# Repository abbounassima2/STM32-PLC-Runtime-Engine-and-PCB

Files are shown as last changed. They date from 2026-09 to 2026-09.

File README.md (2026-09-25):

# STM32 PLC Runtime Engine and Hardware Design

An STM32F407-based PLC runtime engine developed in Embedded C, together with a custom PLC controller PCB and a Renode-based simulation environment.

The project focuses on designing a **reusable PLC runtime platform** rather than a single-purpose STM32 application. The architecture separates the permanent runtime, hardware abstraction, process image, communication, and user control logic.

---

## Project Goal

The main objective is to develop an embedded PLC platform capable of providing the core functions of a programmable industrial controller:

- PLC operating modes
- Cyclic and periodic program execution
- Process-image based I/O
- Digital and analog I/O management
- Retentive PLC variables
- Industrial communication
- Runtime monitoring
- Real-time task management
- Custom PLC hardware
- Firmware simulation and testing

The long-term architecture is based on separating the **permanent PLC runtime** from the **user program**, providing the foundation for a configurable and programmable embedded PLC.

---

## System Architecture

```text
                  PLC User Program
                         │
                         ▼
              ┌─────────────────────┐
              │    PLC Runtime       │
              │                      │
              │  Scheduler           │
              │  Operating Modes     │
              │  Process Image       │
              │  I/O Management      │
              │  Retentive Memory    │
              │  Error Handling      │
              │  Communication       │
              └──────────┬───────────┘
                         │
                         ▼
                    STM32F407
                         │
             ┌───────────┼───────────┐
             ▼           ▼           ▼
          Digital      Analog      RS485 /
             I/O         I/O       Modbus

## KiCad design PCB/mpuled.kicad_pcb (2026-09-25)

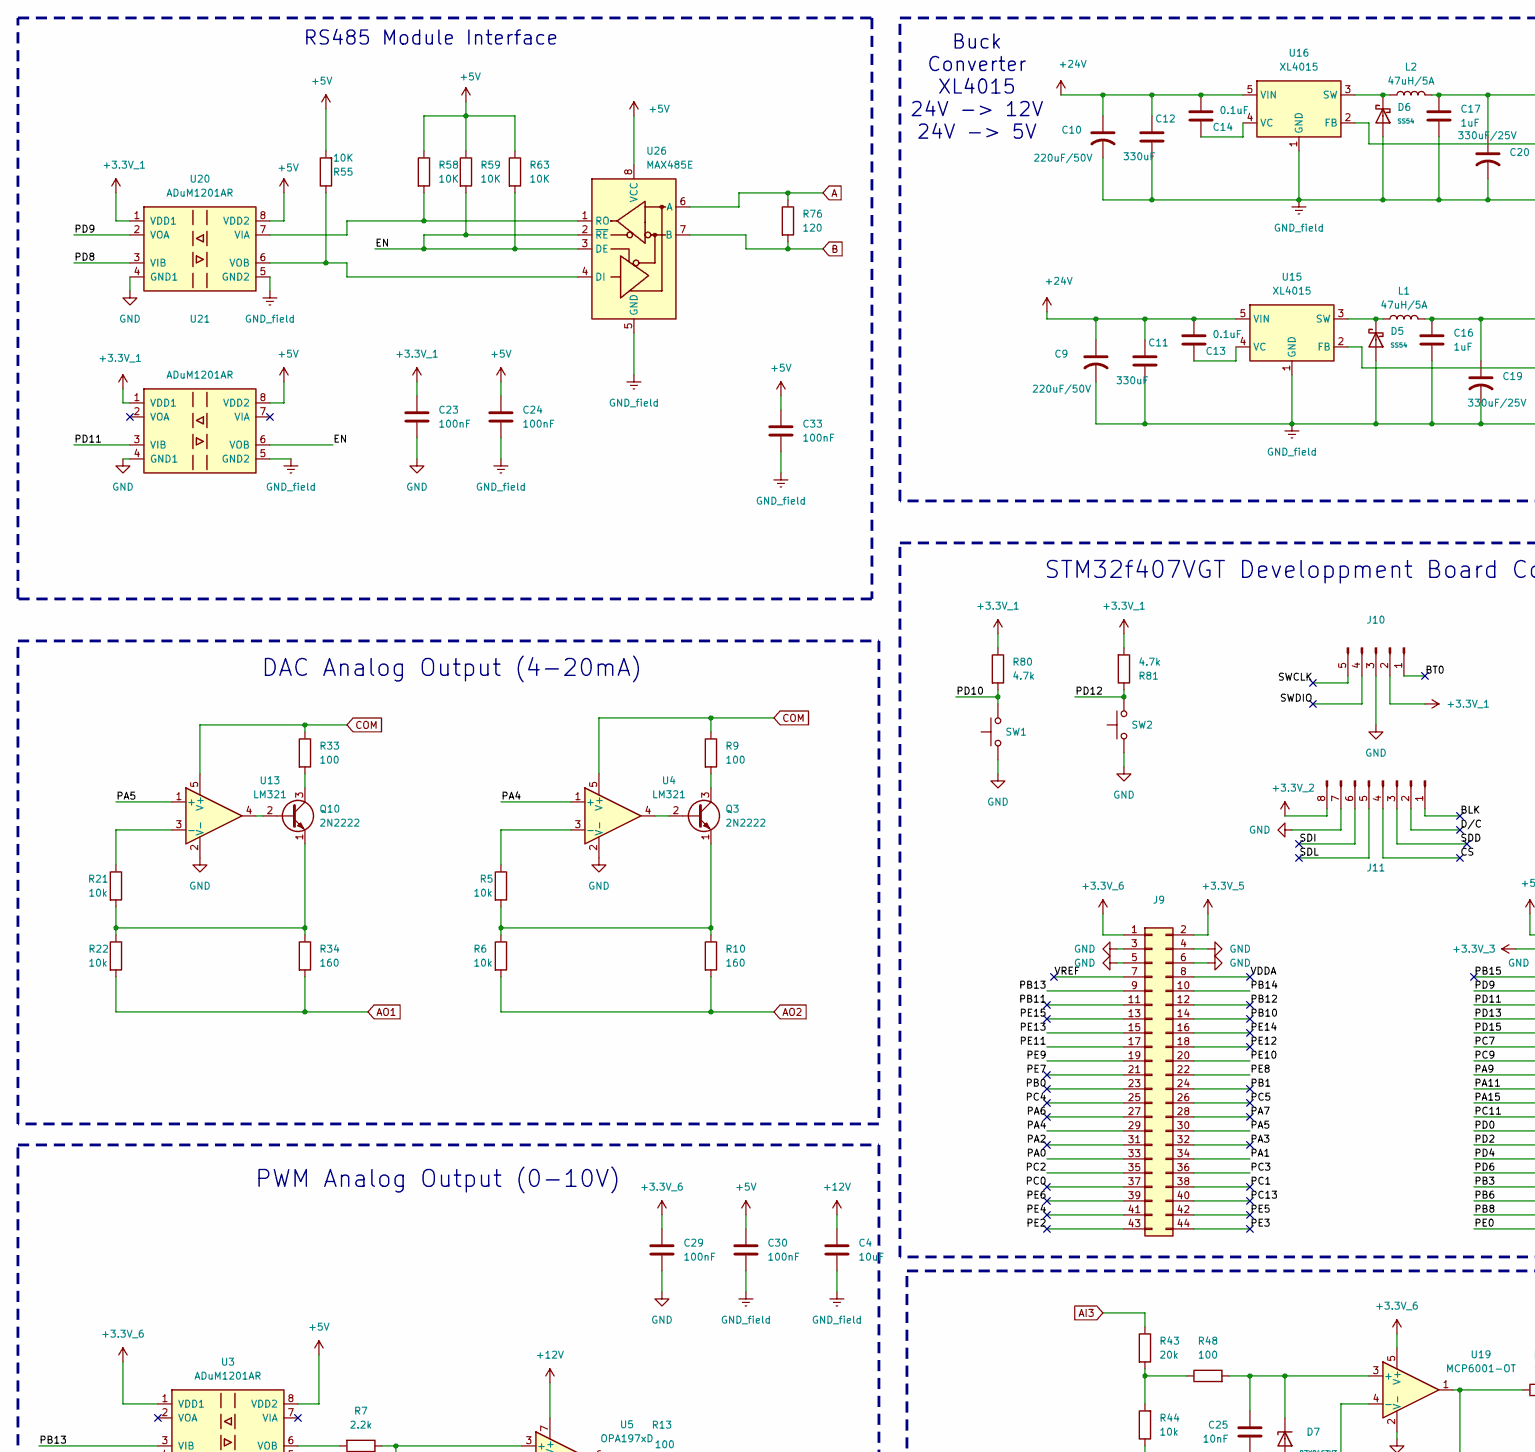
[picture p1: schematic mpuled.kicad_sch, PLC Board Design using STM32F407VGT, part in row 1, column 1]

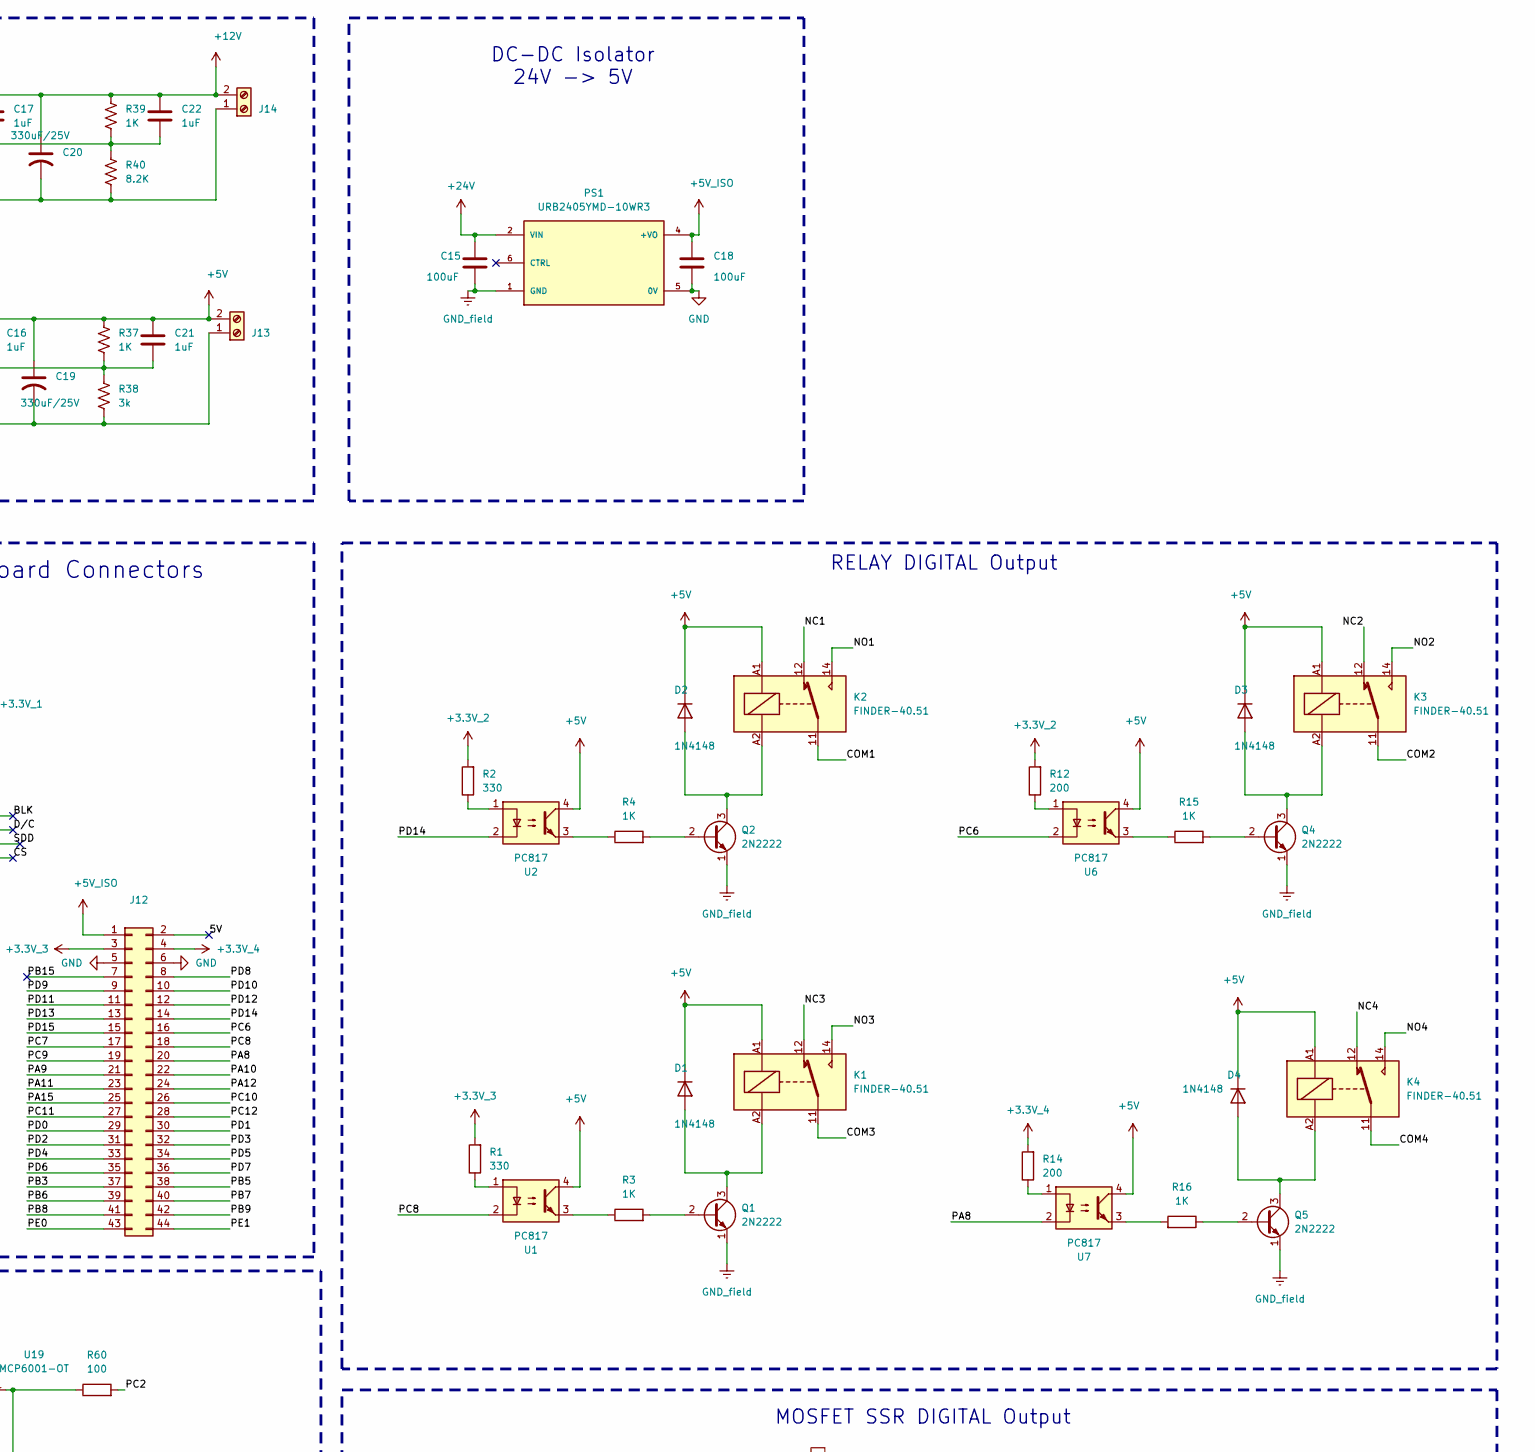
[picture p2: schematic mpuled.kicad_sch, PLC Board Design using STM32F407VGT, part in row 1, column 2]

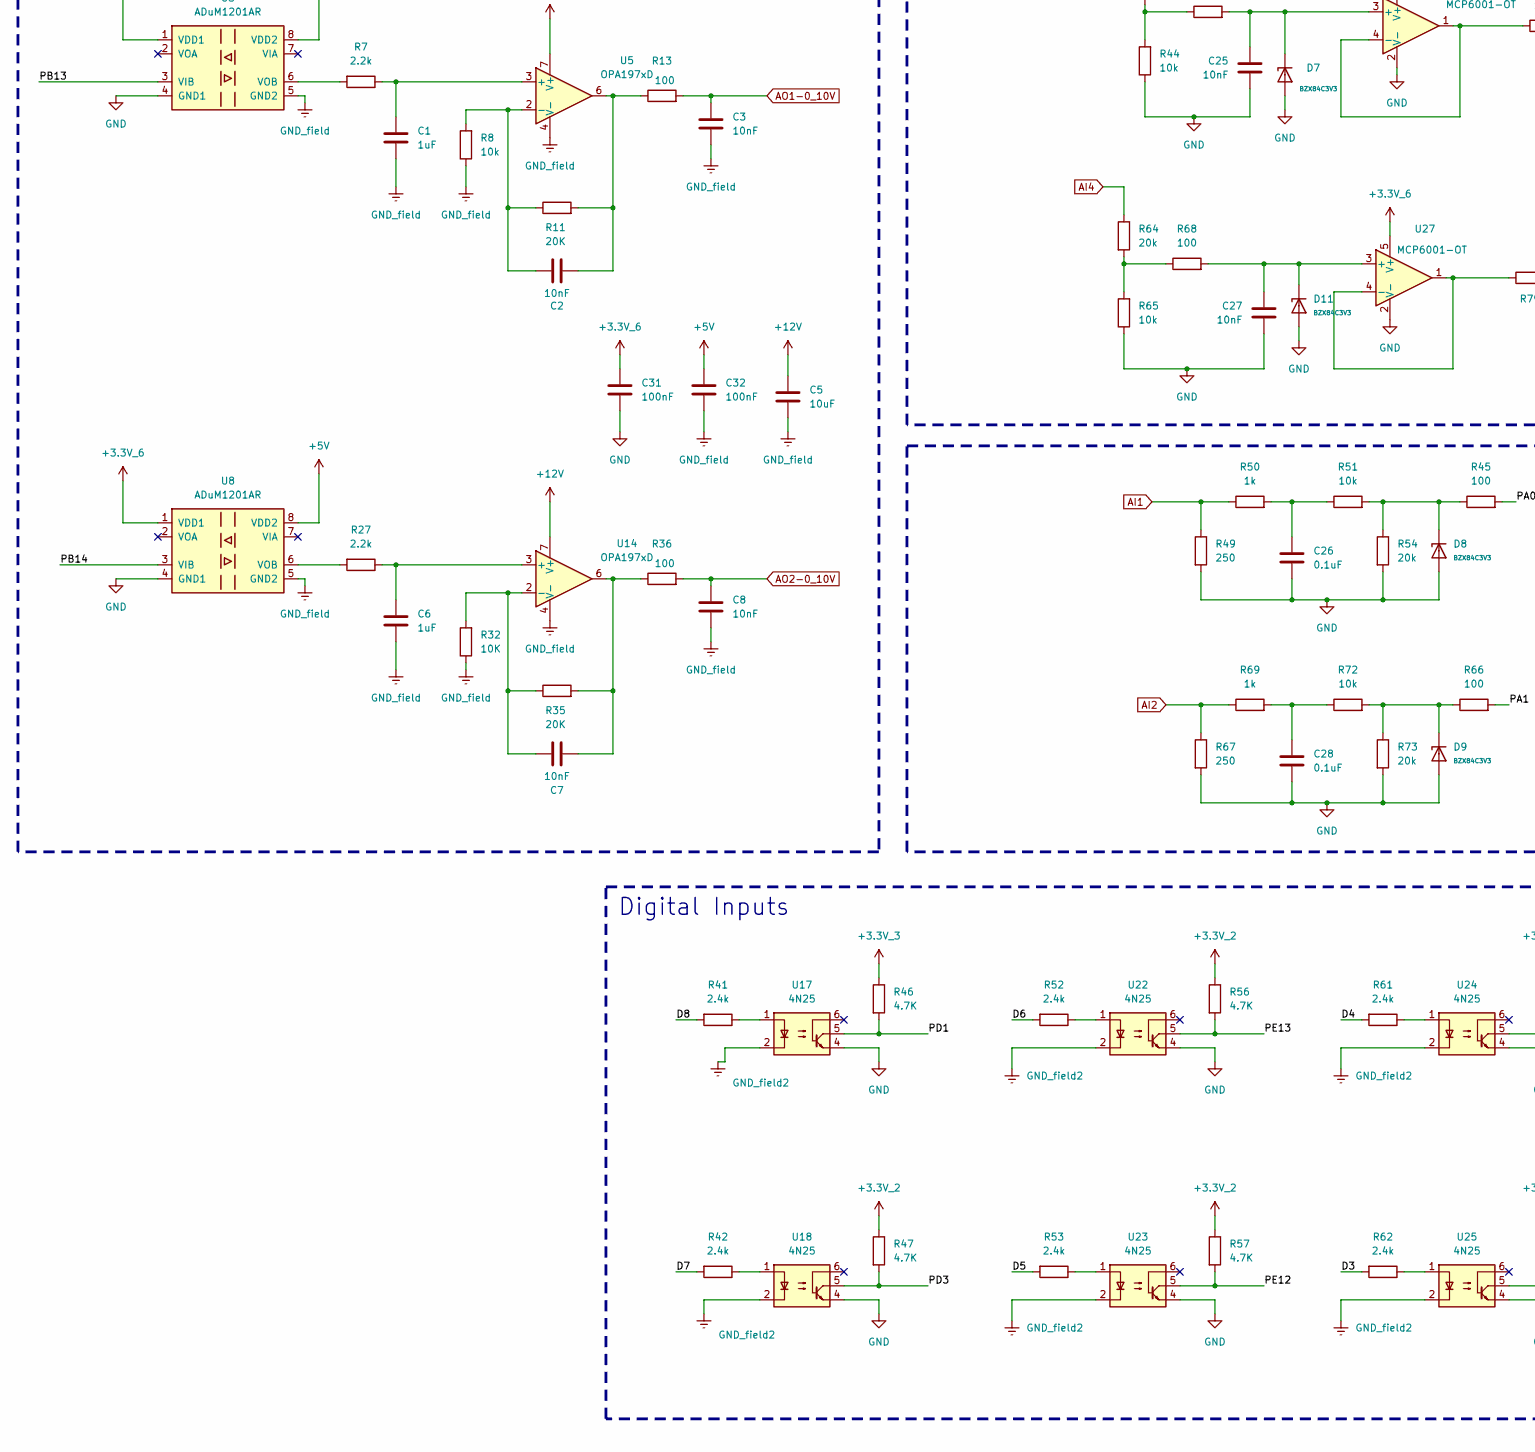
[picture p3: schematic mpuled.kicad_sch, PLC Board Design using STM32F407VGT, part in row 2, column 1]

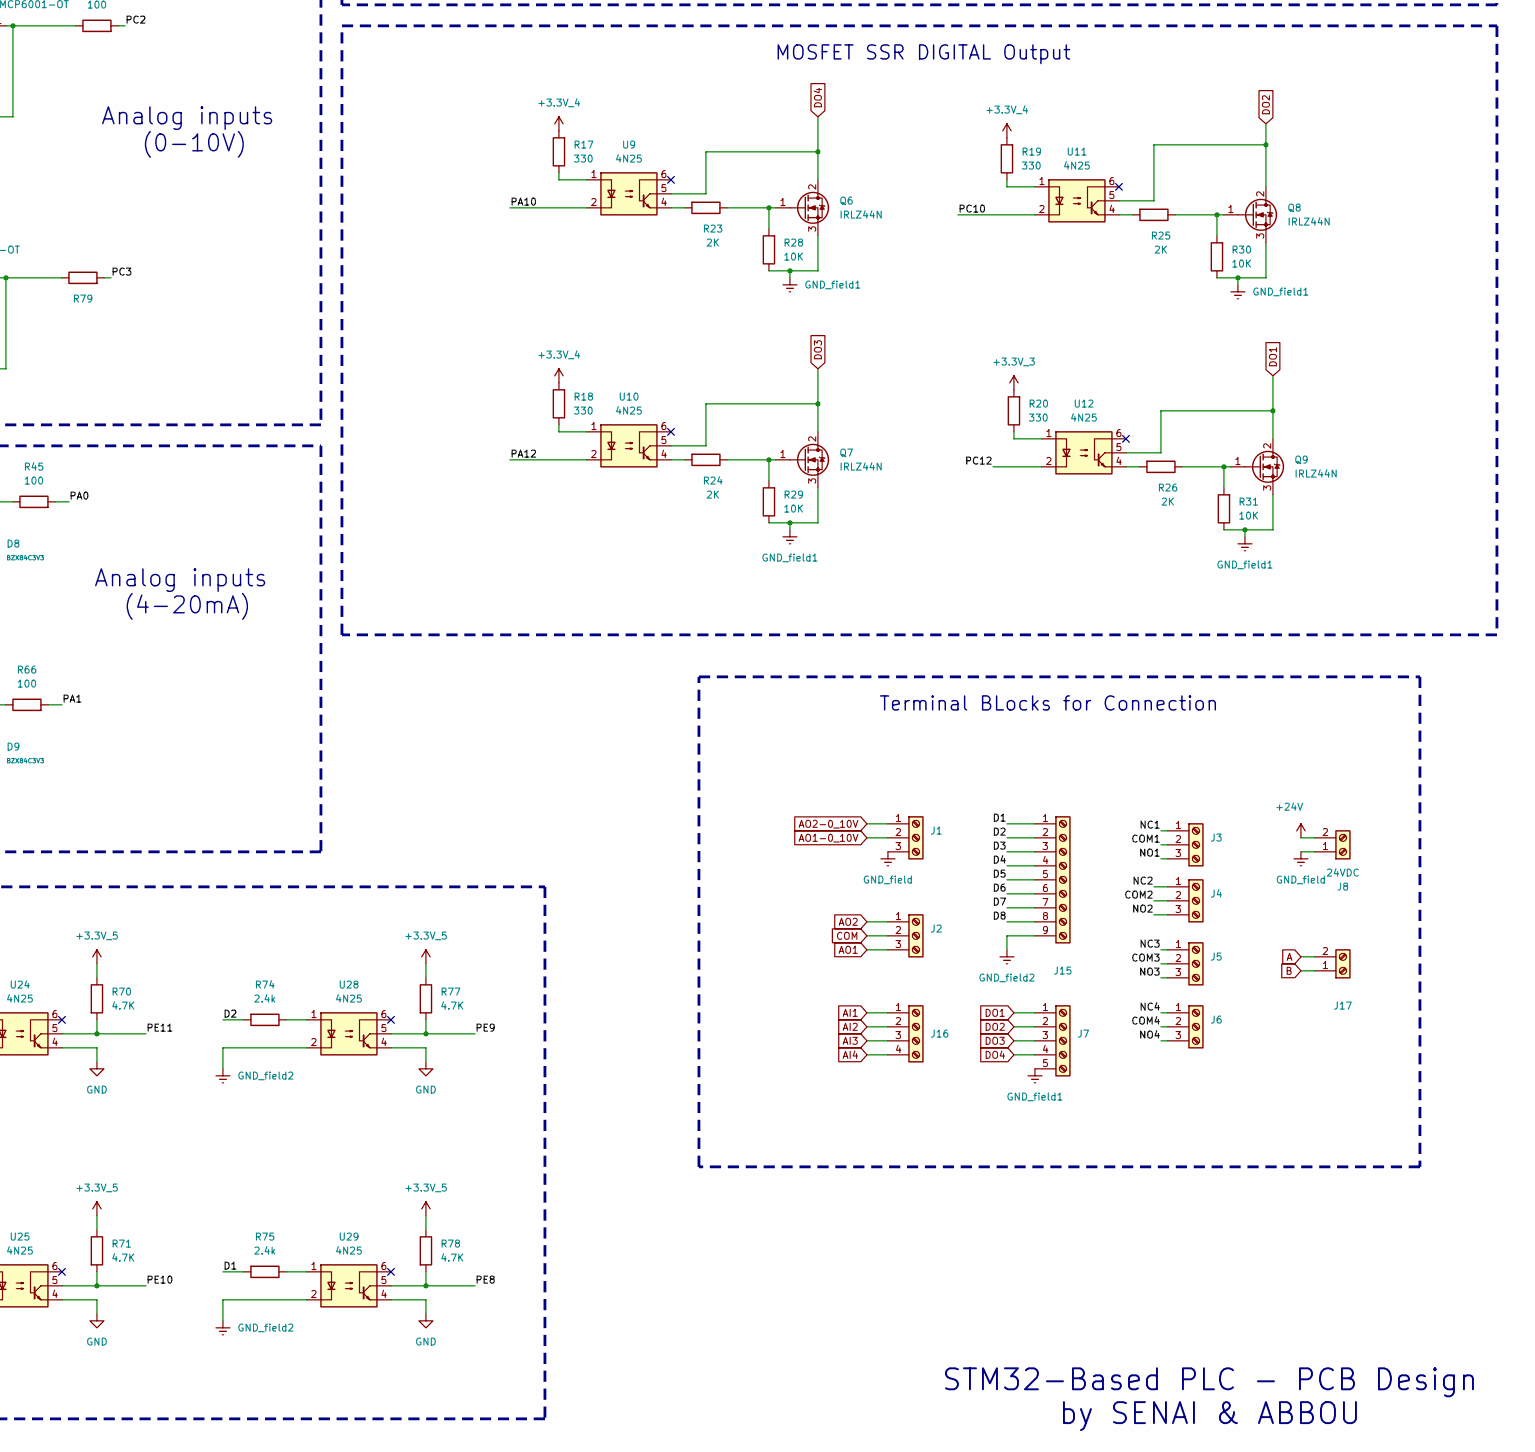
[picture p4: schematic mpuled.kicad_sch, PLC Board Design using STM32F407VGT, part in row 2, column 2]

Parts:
C1, C6, C16, C17, C21, C22: 1uF; C_1206_3216Metric_Pad1.33x1.80mm_HandSolder
C2, C3, C7, C8, C25, C27: 10nF; C_1206_3216Metric_Pad1.33x1.80mm_HandSolder
C4, C5: 10uF; C_1206_3216Metric_Pad1.33x1.80mm_HandSolder
C9, C10: 220uF/50V; C_Radial_D10.0mm_H12.5mm_P5.00mm
C11, C12: 330uF; C_1206_3216Metric_Pad1.33x1.80mm_HandSolder
C13, C14, C26, C28: 0.1uF; C_1206_3216Metric_Pad1.33x1.80mm_HandSolder
C15, C18: 100uF; C_1206_3216Metric_Pad1.33x1.80mm_HandSolder
C19, C20: 330uF/25V; C_Radial_D10.0mm_H12.5mm_P5.00mm
C23, C24, C29, C30, C31, C32, C33: 100nF; C_1206_3216Metric_Pad1.33x1.80mm_HandSolder
D1, D2, D3, D4: 1N4148; D_DO-35_SOD27_P7.62mm_Horizontal
D5, D6: SS54; D_SMA; Forward Voltage (Vf@If) 550mV@5A; Reverse Voltage (Vr) 40V; Part SS54; LCSC C22452
D7, D8, D9, D11: BZX84C3V3; D_SOT-23; Zener Voltage (Range) 3.1V~3.5V; Zener Voltage (Nom) 3.3V; Part BZX84C3V3; LCSC C19077467
J1, J2: Screw_Terminal_01x03; TerminalBlock_Phoenix_MKDS-1,5-3_1x03_P5.00mm_Horizontal
J3, J4, J5, J6: TerminalBlock_Phoenix_MKDS-1,5-3-5.08_1x03_P5.08mm_Horizont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
J7: Screw_Terminal_01x05; TerminalBlock_Phoenix_MKDS-1,5-5-5.08_1x05_P5.08mm_Horizont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
J8: 24VDC; TerminalBlock_Phoenix_MKDS-1,5-2-5.08_1x02_P5.08mm_Horizont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
J9, J12: Conn_02x22_Odd_Even; PinHeader_2x22_P2.54mm_Vertical
J10: PinHeader_1x05_P2.54mm_Vertical
J11: PinHeader_1x08_P2.54mm_Vertical
J13, J14: Screw_Terminal_01x02; TerminalBlock_Phoenix_MKDS-1,5-2_1x02_P5.00mm_Horizontal
J15: Screw_Terminal_01x09; TerminalBlock_Phoenix_MKDS-1,5-9-5.08_1x09_P5.08mm_Horizont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
J16: TerminalBlock_Phoenix_MKDS-1,5-4_1x04_P5.00mm_Horizontal
J17: TerminalBlock_Phoenix_MKDS-1,5-2-5.08_1x02_P5.08mm_Horizont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
K1, K2, K3, K4: FINDER-40.51; Relay_SPDT_Finder_40.51
L1, L2: 47uH/5A; L_Axial_L14.5mm_D5.8mm_P20.32mm_Horizontal_Fastron_HBCC
PS1: URB2405YMD-10WR3; Converter_DCDC_XP_POWER-IAxxxxS_THT; PARTREV 2019.11.13-A/9
Q1, Q4, Q5: 2N2222; SOT-23W_Handsoldering
Q2: 2N2222; TSOT-23_HandSoldering
Q3, Q10: 2N2222; Q_SOT-23
Q6, Q7, Q8, Q9: IRLZ44N; TO-220-3_Vertical
R1, R2, R17, R18, R19, R20: 330; R_1206_3216Metric_Pad1.30x1.75mm_HandSolder
R3, R4, R15, R16, R37, R39: 1K; R_1206_3216Metric_Pad1.30x1.75mm_HandSolder
R5, R6, R8, R21, R22, R44, R51, R65, R72: 10k; R_1206_3216Metric_Pad1.30x1.75mm_HandSolder
R7, R27: 2.2k; R_1206_3216Metric_Pad1.30x1.75mm_HandSolder
R9, R13, R33, R36, R45, R60, R66, R79: 100; R_1206_3216Metric_Pad1.30x1.75mm_HandSolder
R10, R34: 160; R_1206_3216Metric_Pad1.30x1.75mm_HandSolder
R11, R35: 20K; R_1206_3216Metric_Pad1.30x1.75mm_HandSolder
R12, R14: 200; R_1206_3216Metric_Pad1.30x1.75mm_HandSolder
R23, R24, R25, R26: 2K; R_1206_3216Metric_Pad1.30x1.75mm_HandSolder
R28, R29, R30, R31, R32, R55, R58, R59, R63: 10K; R_1206_3216Metric_Pad1.30x1.75mm_HandSolder
R38: 3k; R_1206_3216Metric_Pad1.30x1.75mm_HandSolder
R40: 8.2K; R_1206
R41, R42, R52, R53, R61, R62, R74, R75: 2.4k; R_1206_3216Metric_Pad1.30x1.75mm_HandSolder
R43, R54, R73: 20k; R_1206_3216Metric_Pad1.30x1.75mm_HandSolder
R46, R47, R56, R57, R70, R71, R77, R78: 4.7K; R_1206_3216Metric_Pad1.30x1.75mm_HandSolder
R48, R68: 100; R_1206_3216Metric
R49, R67: 250; R_1206_3216Metric_Pad1.30x1.75mm_HandSolder
R50, R69: 1k; R_1206_3216Metric_Pad1.30x1.75mm_HandSolder
R64: 20k; R_1206_3216Metric
R76: 120; R_1206_3216Metric_Pad1.30x1.75mm_HandSolder
R80, R81: 4.7k; R_1206_3216Metric_Pad1.30x1.75mm_HandSolder
SW1, SW2: SW_Omron_B3FS; SW_SPST_Omron_B3FS-100xP
U1, U2, U6, U7: PC817; DIP-4_W7.62mm
U3, U8, U20, U21: ADuM1201AR; SOIC-8_3.9x4.9mm_P1.27mm
U4, U13: LM321; SOT-23-5_HandSoldering
U5, U14: OPA197xD; SOIC-8_3.9x4.9mm_P1.27mm
U9, U10, U11, U12, U17, U18, U22, U23, U24, U25, U28, U29: 4N25; DIP-6_W7.62mm
U15, U16: XL4015; TO-263-5_TabPin3
U19, U27: MCP6001-OT; SOT-23-5
U26: MAX485E; SOIC-8_3.9x4.9mm_P1.27mm

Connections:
+3.3V_1: C23.1, J10.2, R80.1, R81.2, U20.1 (VDD1), U21.1 (VDD1)
+3.3V_2: J11.8, R2.2, R12.2, R47.1, R56.1, R57.1
+3.3V_3: J12.3, R1.2, R20.2, R46.1
+3.3V_4: J12.4, R14.2, R17.2, R18.2, R19.2
+3.3V_5: J9.2, R70.1, R71.1, R77.1, R78.1
+3.3V_6: C29.1, C31.1, J9.1, U3.1 (VDD1), U8.1 (VDD1), U19.5 (V+), U27.5 (V+)
+5V: C16.1, C19.1, C21.1, C24.1, C30.1, C32.1, C33.1, D1.1 (K), D2.1 (K), D3.1 (K), D4.1 (K), J13.2, K1.A1, K2.A1, K3.A1, K4.A1, L1.2, R37.1, R55.2, R58.1, R59.1, R63.1, U1.4, U2.4, U3.8 (VDD2), U6.4, U7.4, U8.8 (VDD2), U20.8 (VDD2), U21.8 (VDD2), U26.8 (VCC)
+5V_ISO: C18.1, J12.1, PS1.4 (+VO)
+12V: C4.1, C5.1, C17.1, C20.1, C22.1, J14.2, L2.2, R39.1, U5.7 (V+), U14.7 (V+)
+24V: C9.1, C10.1, C11.1, C12.1, C13.1, C14.1, C15.1, J8.2, PS1.2 (VIN), U15.5 (VIN), U16.5 (VIN)
/5V: J12.2
/BLK: J11.1
/BT0: J10.1
/COM1: J3.2, K2.11
/COM2: J4.2, K3.11
/COM3: J5.2, K1.11
/COM4: J6.2, K4.11
/CS: J11.4
/D1: J15.1, R75.2
/D2: J15.2, R74.2
/D3: J15.3, R62.2
/D4: J15.4, R61.2
/D5: J15.5, R53.2
/D6: J15.6, R52.2
/D7: J15.7, R42.2
/D8: J15.8, R41.2
/D/C: J11.2
/EN: R59.2, R63.2, U21.6 (VOB), U26.2 (~RE), U26.3 (DE)
/NC1: J3.1, K2.12
/NC2: J4.1, K3.12
/NC3: J5.1, K1.12
/NC4: J6.1, K4.12
/NO1: J3.3, K2.14
/NO2: J4.3, K3.14
/NO3: J5.3, K1.14
/NO4: J6.3, K4.14
/PA0: J9.33, R45.2
/PA1: J9.34, R66.2
/PA2: J9.31
/PA3: J9.32
/PA4: J9.29, U4.1 (+)
/PA5: J9.30, U13.1 (+)
/PA6: J9.27
/PA7: J9.28
/PA8: J12.20, U7.2
/PA9: J12.21
/PA10: J12.22, U9.2
/PA11: J12.23
/PA12: J12.24, U10.2
/PA15: J12.25
/PB0: J9.23
/PB1: J9.24
/PB3: J12.37
/PB5: J12.38
/PB6: J12.39
/PB7: J12.40
/PB8: J12.41
/PB9: J12.42
/PB10: J9.14
/PB11: J9.11
/PB12: J9.12
/PB13: J9.9, U3.3 (VIB)
/PB14: J9.10, U8.3 (VIB)
/PB15: J12.7
/PC0: J9.37
/PC1: J9.38
/PC2: J9.35, R60.2
/PC3: J9.36, R79.2
/PC4: J9.25
/PC5: J9.26
/PC6: J12.16, U6.2
/PC7: J12.17
/PC8: J12.18, U1.2
/PC9: J12.19
/PC10: J12.26, U11.2
/PC11: J12.27
/PC12: J12.28, U12.2
/PC13: J9.40
/PD0: J12.29
/PD1: J12.30, R46.2, U17.5
/PD2: J12.31
/PD3: J12.32, R47.2, U18.5
/PD4: J12.33
/PD5: J12.34
/PD6: J12.35
/PD7: J12.36
/PD8: J12.8, U20.3 (VIB)
/PD9: J12.9, U20.2 (VOA)
/PD10: J12.10, R80.2, SW1.2
/PD11: J12.11, U21.3 (VIB)
/PD12: J12.12, R81.1, SW2.2
/PD13: J12.13
/PD14: J12.14, U2.2
/PD15: J12.15
/PE0: J12.43
/PE1: J12.44
/PE2: J9.43
/PE3: J9.44
/PE4: J9.41
/PE5: J9.42
/PE6: J9.39
/PE7: J9.21
/PE8: J9.22, R78.2, U29.5
/PE9: J9.19, R77.2, U28.5
/PE10: J9.20, R71.2, U25.5
/PE11: J9.17, R70.2, U24.5
/PE12: J9.18, R57.2, U23.5
/PE13: J9.15, R56.2, U22.5
/PE14: J9.16
/PE15: J9.13
/SDD: J11.3
/SDI: J11.6
/SDL: J11.5
/SWCLK: J10.5
/SWDIO: J10.4
/VDDA: J9.8
/VREF: J9.7
A: J17.2, R76.1, U26.6 (A)
AI1: J16.1, R49.1, R50.1
AI2: J16.2, R67.1, R69.1
AI3: J16.3, R43.1
AI4: J16.4, R64.1
AO1: J2.3, R22.2, R34.2
AO1-0_10V: C3.1, J1.2, R13.2
AO2: J2.1, R6.2, R10.2
AO2-0_10V: C8.1, J1.1, R36.2
B: J17.1, R76.2, U26.7 (B)
COM: J2.2, R9.1, R33.1, U4.5 (V+), U13.5 (V+)
DO1: J7.1, Q9.2 (D), U12.5
DO2: J7.2, Q8.2 (D), U11.5
DO3: J7.3, Q7.2 (D), U10.5
DO4: J7.4, Q6.2 (D), U9.5
GND: C18.2, C23.2, C25.2, C26.2, C27.2, C28.2, C29.2, C31.2, D7.1, D8.1, D9.1, D11.1, J9.3, J9.4, J9.5, J9.6, J10.3, J11.7, J12.5, J12.6, PS1.5 (0V), R44.1, R49.2, R54.2, R65.1, R67.2, R73.2, SW1.1, SW2.1, U3.4 (GND1), U4.2 (V-), U8.4 (GND1), U13.2 (V-), U17.4, U18.4, U19.2 (V-), U20.4 (GND1), U21.4 (GND1), U22.4, U23.4, U24.4, U25.4, U27.2 (V-), U28.4, U29.4
GND_field: C1.2, C3.2, C4.2, C5.2, C6.2, C8.2, C9.2, C10.2, C11.2, C12.2, C15.2, C16.2, C17.2, C19.2, C20.2, C24.2, C30.2, C32.2, C33.2, D5.2, D6.2, J1.3, J8.1, J13.1, J14.1, PS1.1 (GND), Q1.1 (E), Q2.1 (E), Q4.1 (E), Q5.1 (E), R8.1, R32.1, R38.2, R40.2, U3.5 (GND2), U5.4 (V-), U8.5 (GND2), U14.4 (V-), U15.1 (GND), U16.1 (GND), U20.5 (GND2), U21.5 (GND2), U26.5 (GND)
GND_field1: J7.5, Q6.3 (S), Q7.3 (S), Q8.3 (S), Q9.3 (S), R28.1, R29.1, R30.1, R31.1
GND_field2: J15.9, U17.2, U18.2, U22.2, U23.2, U24.2, U25.2, U28.2, U29.2
unnamed: C2.2, R11.2, R13.1, U5.6
unnamed: C7.2, R35.2, R36.1, U14.6
unnamed: C26.1, R50.2, R51.1
unnamed: C28.1, R69.2, R72.1
unnamed: D1.2 (A), K1.A2, Q1.3 (C)
unnamed: D2.2 (A), K2.A2, Q2.3 (C)
unnamed: D3.2 (A), K3.A2, Q4.3 (C)
unnamed: D4.2 (A), K4.A2, Q5.3 (C)
unnamed: D8.3, R45.1, R51.2, R54.1
unnamed: D9.3, R66.1, R72.2, R73.1
unnamed: Q1.2 (B), R3.2
unnamed: Q2.2 (B), R4.2
unnamed: Q3.2 (B), U4.4
unnamed: Q3.3 (C), R9.2
unnamed: Q3.1 (E), R5.2, R6.1, R10.1
unnamed: Q4.2 (B), R15.2
unnamed: Q5.2 (B), R16.1
unnamed: Q6.1 (G), R23.1, R28.2
unnamed: Q7.1 (G), R24.1, R29.2
unnamed: Q8.1 (G), R25.1, R30.2
unnamed: Q9.1 (G), R26.1, R31.2
unnamed: Q10.2 (B), U13.4
unnamed: Q10.3 (C), R33.2
unnamed: Q10.1 (E), R21.2, R22.1, R34.1
unnamed: R1.1, U1.1
unnamed: R2.1, U2.1
unnamed: R3.1, U1.3
unnamed: R4.1, U2.3
unnamed: R12.1, U6.1
unnamed: R14.1, U7.1
unnamed: R15.1, U6.3
unnamed: R16.2, U7.3
unnamed: R17.1, U9.1
unnamed: R18.1, U10.1
unnamed: R19.1, U11.1
unnamed: R20.1, U12.1
unnamed: R23.2, U9.4
unnamed: R24.2, U10.4
unnamed: R25.2, U11.4
unnamed: R26.2, U12.4
unnamed: R41.1, U17.1
unnamed: R42.1, U18.1
unnamed: R43.2, R44.2, R48.1
unnamed: R52.1, U22.1
unnamed: R53.1, U23.1
unnamed: R61.1, U24.1
unnamed: R62.1, U25.1
unnamed: R64.2, R65.2, R68.1
unnamed: R74.1, U28.1
unnamed: R75.1, U29.1
unnamed: R7.2, U3.6 (VOB)
unnamed: R5.1, U4.3 (-)
unnamed: C1.1, R7.1, U5.3 (+)
unnamed: C2.1, R8.2, R11.1, U5.2 (-)
unnamed: R27.2, U8.6 (VOB)
unnamed: R21.1, U13.3 (-)
unnamed: C6.1, R27.1, U14.3 (+)
unnamed: C7.1, R32.2, R35.1, U14.2 (-)
unnamed: C21.2, R37.2, R38.1, U15.2 (FB)
unnamed: D5.1, L1.1, U15.3 (SW)
unnamed: C13.2, U15.4 (VC)
unnamed: C22.2, R39.2, R40.1, U16.2 (FB)
unnamed: D6.1, L2.1, U16.3 (SW)
unnamed: C14.2, U16.4 (VC)
unnamed: C25.1, D7.3, R48.2, U19.3 (+)
unnamed: R60.1, U19.1, U19.4 (-)
unnamed: R58.2, U20.7 (VIA), U26.1 (RO)
unnamed: R55.1, U20.6 (VOB), U26.4 (DI)
unnamed: C27.1, D11.3, R68.2, U27.3 (+)
unnamed: R79.1, U27.1, U27.4 (-)

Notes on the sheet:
DC-DC Isolator 24V -> 5V
RELAY DIGITAL Output
Buck Converter XL4015 24V -> 12V 24V -> 5V
DAC Analog Output (4-20mA)
RS485 Module Interface
Analog inputs (4-20mA)
STM32-Based PLC - PCB Design by SENAI & ABBOU
Terminal BLocks for Connection
Digital Inputs
MOSFET SSR DIGITAL Output
Analog inputs (0-10V)
PWM Analog Output (0-10V)
STM32f407VGT Developpment Board Connectors

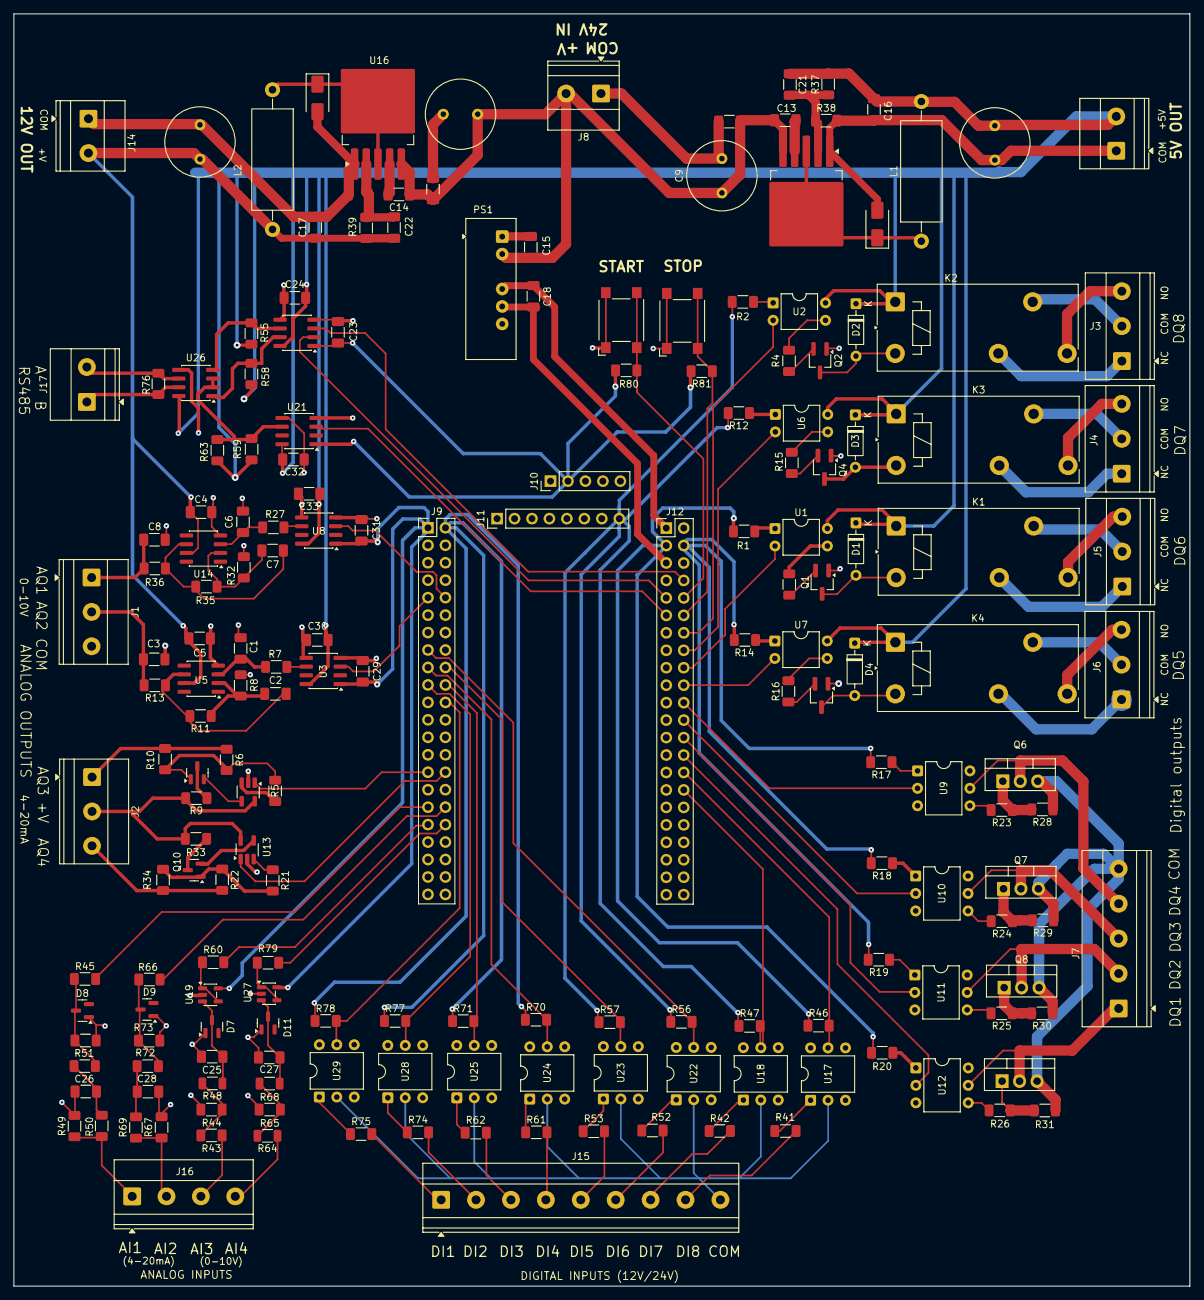
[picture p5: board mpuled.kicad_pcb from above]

Board: 2 copper layers, 171.1 x 185.1 mm, 189 parts (0 on the bottom side), 149 nets.

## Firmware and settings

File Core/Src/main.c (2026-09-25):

#include "main.h"
#include "cmsis_os.h"

#include "board.h"
#include "plc_scheduler.h"
#include "comm_rs485.h"
#include "retentive.h"

/* --- Peripheral handles  --- */
ADC_HandleTypeDef  hadc1;
DAC_HandleTypeDef  hdac;
TIM_HandleTypeDef  htim2;
TIM_HandleTypeDef  htim12;
UART_HandleTypeDef huart4;
UART_HandleTypeDef huart3;

/* --- RTOS thread handles/attributes --- */
osThreadId_t defaultTaskHandle;
const osThreadAttr_t defaultTask_attributes = {
    .name = "defaultTask",
    .stack_size = 512 * 4,
    .priority = (osPriority_t) osPriorityNormal,
};

osThreadId_t ob30TaskHandle;
const osThreadAttr_t ob30Task_attributes = {
    .name = "ob30Task",
    .stack_size = 512 * 4,
    .priority = (osPriority_t) osPriorityHigh,
};

osThreadId_t commTaskHandle;
const osThreadAttr_t commTask_attributes = {
    .name = "commTask",
    .stack_size = 256 * 4,
    .priority = (osPriority_t) osPriorityLow,
};


void SystemClock_Config(void);
static void MX_GPIO_Init(void);
static void MX_ADC1_Init(void);
static void MX_DAC_Init(void);
static void MX_TIM2_Init(void);
static void MX_TIM12_Init(void);
static void MX_UART4_Init(void);
static void MX_USART3_UART_Init(void);

int main(void)
{
    HAL_Init();
    SystemClock_Config();

    MX_GPIO_Init();
    MX_ADC1_Init();
    MX_DAC_Init();
    MX_TIM2_Init();
    MX_TIM12_Init();
    MX_UART4_Init();
    MX_USART3_UART_Init();

    PLC_RS485_Init();

    osKernelInitialize();

    defaultTaskHandle = osThreadNew(state_machine, NULL, &defaultTask_attributes);
    ob30TaskHandle     = osThreadNew(OB30_Task, NULL, &ob30Task_attributes);
    commTaskHandle      = osThreadNew(CommTask, NULL, &commTask_attributes);

    osKernelStart();

    while (1) { }
}




void HAL_TIM_PeriodElapsedCallback(TIM_HandleTypeDef *htim)
{
    if (htim->Instance == TIM2) {
        OB80_ISR_Handler();
    }
}



void Error_Handler(void)
{
    __disable_irq();
    while (1) { }
}

/* --- printf() redirection to UART4, used by update_output()'s
 *     diagnostic line in process_image.c --- */
int _write(int file, char *ptr, int len)
{
    (void)file;
    HAL_UART_Transmit(&huart4, (uint8_t *)ptr, len, HAL_MAX_DELAY);
    return len;
}

void SystemClock_Config(void)
{
  RCC_OscInitTypeDef RCC_OscInitStruct = {0};
  RCC_ClkInitTypeDef RCC_ClkInitStruct = {0};


  __HAL_RCC_PWR_CLK_ENABLE();
  __HAL_PWR_VOLTAGESCALING_CONFIG(PWR_REGULATOR_VOLTAGE_SCALE1);


  RCC_OscInitStruct.OscillatorType = RCC_OSCILLATORTYPE_HSI;
  RCC_OscInitStruct.HSIState = RCC_HSI_ON;
  RCC_OscInitStruct.HSICalibrationValue = RCC_HSICALIBRATION_DEFAULT;
  RCC_OscInitStruct.PLL.PLLState = RCC_PLL_ON;
  RCC_OscInitStruct.PLL.PLLSource = RCC_PLLSOURCE_HSI;
  RCC_OscInitStruct.PLL.PLLM = 16;
  RCC_OscInitStruct.PLL.PLLN = 336;
  RCC_OscInitStruct.PLL.PLLP = RCC_PLLP_DIV2;
  RCC_OscInitStruct.PLL.PLLQ = 4;
  if (HAL_RCC_OscConfig(&RCC_OscInitStruct) != HAL_OK)
  {
    Error_Handler();
  }


  RCC_ClkInitStruct.ClockType = RCC_CLOCKTYPE_HCLK|RCC_CLOCKTYPE_SYSCLK
                              |RCC_CLOCKTYPE_PCLK1|RCC_CLOCKTYPE_PCLK2;
  RCC_ClkInitStruct.SYSCLKSource = RCC_SYSCLKSOURCE_PLLCLK;
  RCC_ClkInitStruct.AHBCLKDivider = RCC_SYSCLK_DIV1;
  RCC_ClkInitStruct.APB1CLKDivider = RCC_HCLK_DIV4;
  RCC_ClkInitStruct.APB2CLKDivider = RCC_HCLK_DIV2;

  if (HAL_RCC_ClockConfig(&RCC_ClkInitStruct, FLASH_LATENCY_5) != HAL_OK)
  {
    Error_Handler();
  }
}


static void MX_ADC1_Init(void)
{



  ADC_ChannelConfTypeDef sConfig = {0};
  hadc1.Instance = ADC1;
  hadc1.Init.ClockPrescaler = ADC_CLOCK_SYNC_PCLK_DIV4;
  hadc1.Init.Resolution = ADC_RESOLUTION_12B;
  hadc1.Init.ScanConvMode = DISABLE;
  hadc1.Init.ContinuousConvMode = DISABLE;
  hadc1.Init.DiscontinuousConvMode = DISABLE;
  hadc1.Init.ExternalTrigConvEdge = ADC_EXTERNALTRIGCONVEDGE_NONE;
  hadc1.Init.ExternalTrigConv = ADC_SOFTWARE_START;
  hadc1.Init.DataAlign = ADC_DATAALIGN_RIGHT;
  hadc1.Init.NbrOfConversion = 1;
  hadc1.Init.DMAContinuousRequests = DISABLE;
  hadc1.Init.EOCSelection = ADC_EOC_SINGLE_CONV;
  if (HAL_ADC_Init(&hadc1) != HAL_OK)
  {
    Error_Handler();
  }


  sConfig.Channel = ADC_CHANNEL_0;
  sConfig.Rank = 1;
  sConfig.SamplingTime = ADC_SAMPLETIME_3CYCLES;
  if (HAL_ADC_ConfigChannel(&hadc1, &sConfig) != HAL_OK)
  {
    Error_Handler();
  }


}

static void MX_DAC_Init(void)
{



  DAC_ChannelConfTypeDef sConfig = {0};

  hdac.Instance = DAC;
  if (HAL_DAC_Init(&hdac) != HAL_OK)
  {
    Error_Handler();
  }

  sConfig.DAC_Trigger = DAC_TRIGGER_NONE;
  sConfig.DAC_OutputBuffer = DAC_OUTPUTBUFFER_ENABLE;
  if (HAL_DAC_ConfigChannel(&hdac, &sConfig, DAC_CHANNEL_1) != HAL_OK)
  {
    Error_Handler();
  }

  if (HAL_DAC_ConfigChannel(&hdac, &sConfig, DAC_CHANNEL_2) != HAL_OK)
  {
    Error_Handler();
  }


}


static void MX_TIM2_Init(void)
{



  TIM_ClockConfigTypeDef sClockSourceConfig = {0};
  TIM_MasterConfigTypeDef sMasterConfig = {0};
  htim2.Instance = TIM2;
  htim2.Init.Prescaler = 1599;
  htim2.Init.CounterMode = TIM_COUNTERMODE_UP;
  htim2.Init.Period = 5999;
  htim2.Init.ClockDivision = TIM_CLOCKDIVISION_DIV1;
  htim2.Init.AutoReloadPreload = TIM_AUTORELOAD_PRELOAD_DISABLE;
  if (HAL_TIM_Base_Init(&htim2) != HAL_OK)
  {
    Error_Handler();
  }
  sClockSourceConfig.ClockSource = TIM_CLOCKSOURCE_INTERNAL;
  if (HAL_TIM_ConfigClockSource(&htim2, &sClockSourceConfig) != HAL_OK)
  {
    Error_Handler();
  }
  sMasterConfig.MasterOutputTrigger = TIM_TRGO_RESET;
  sMasterConfig.MasterSlaveMode = TIM_MASTERSLAVEMODE_DISABLE;
  if (HAL_TIMEx_MasterConfigSynchronization(&htim2, &sMasterConfig) != HAL_OK)
  {
    Error_Handler();
  }


}

static void MX_TIM12_Init(void)
{



  TIM_ClockConfigTypeDef sClockSourceConfig = {0};
  TIM_OC_InitTypeDef sConfigOC = {0};


  htim12.Instance = TIM12;
  htim12.Init.Prescaler = 0;
  htim12.Init.CounterMode = TIM_COUNTERMODE_UP;
  htim12.Init.Period = 4095;
  htim12.Init.ClockDivision = TIM_CLOCKDIVISION_DIV1;
  htim12.Init.AutoReloadPreload = TIM_AUTORELOAD_PRELOAD_ENABLE;
  if (HAL_TIM_Base_Init(&htim12) != HAL_OK)
  {
    Error_Handler();
  }
  sClockSourceConfig.ClockSource = TIM_CLOCKSOURCE_INTERNAL;
  if (HAL_TIM_ConfigClockSource(&htim12, &sClockSourceConfig) != HAL_OK)
  {
    Error_Handler();
  }
  if (HAL_TIM_PWM_Init(&htim12) != HAL_OK)
  {
    Error_Handler();
  }
  sConfigOC.OCMode = TIM_OCMODE_PWM1;
  sConfigOC.Pulse = 0;
  sConfigOC.OCPolarity = TIM_OCPOLARITY_HIGH;
  sConfigOC.OCFastMode = TIM_OCFAST_DISABLE;
  if (HAL_TIM_PWM_ConfigChannel(&htim12, &sConfigOC, TIM_CHANNEL_1) != HAL_OK)
  {
    Error_Handler();
  }
  if (HAL_TIM_PWM_ConfigChannel(&htim12, &sConfigOC, TIM_CHANNEL_2) != HAL_OK)
  {
    Error_Handler();
  }

  HAL_TIM_MspPostInit(&htim12);

}

static void MX_UART4_Init(void)
{


  huart4.Instance = UART4;
  huart4.Init.BaudRate = 115200;
  huart4.Init.WordLength = UART_WORDLENGTH_8B;
  huart4.Init.StopBits = UART_STOPBITS_1;
  huart4.Init.Parity = UART_PARITY_NONE;
  huart4.Init.Mode = UART_MODE_TX_RX;
  huart4.Init.HwFlowCtl = UART_HWCONTROL_NONE;
  huart4.Init.OverSampling = UART_OVERSAMPLING_16;
  if (HAL_UART_Init(&huart4) != HAL_OK)
  {
    Error_Handler();
  }


}

static void MX_USART3_UART_Init(void)
{


  huart3.Instance = USART3;
  huart3.Init.BaudRate = 115200;
  huart3.Init.WordLength = UART_WORDLENGTH_8B;
  huart3.Init.StopBits = UART_STOPBITS_1;
  huart3.Init.Parity = UART_PARITY_NONE;
  huart3.Init.Mode = UART_MODE_TX_RX;
  huart3.Init.HwFlowCtl = UART_HWCONTROL_NONE;
  huart3.Init.OverSampling = UART_OVERSAMPLING_16;
  if (HAL_UART_Init(&huart3) != HAL_OK)
  {
    Error_Handler();
  }


}


static void MX_GPIO_Init(void)
{
  GPIO_InitTypeDef GPIO_InitStruct = {0};

  __HAL_RCC_GPIOC_CLK_ENABLE();
  __HAL_RCC_GPIOA_CLK_ENABLE();
  __HAL_RCC_GPIOE_CLK_ENABLE();
  __HAL_RCC_GPIOB_CLK_ENABLE();
  __HAL_RCC_GPIOD_CLK_ENABLE();

  /*Configure GPIO pin Output Level */
  HAL_GPIO_WritePin(GPIOD, GPIO_PIN_11|GPIO_PIN_14, GPIO_PIN_RESET);

  /*Configure GPIO pin Output Level */
  HAL_GPIO_WritePin(GPIOC, GPIO_PIN_6|GPIO_PIN_8|GPIO_PIN_12, GPIO_PIN_RESET);

  /*Configure GPIO pin Output Level */
  HAL_GPIO_WritePin(GPIOA, GPIO_PIN_8|GPIO_PIN_10|GPIO_PIN_12, GPIO_PIN_RESET);

  /*Configure GPIO pins : PE8 PE9 PE10 PE11
                           PE12 PE13 */
  GPIO_InitStruct.Pin = GPIO_PIN_8|GPIO_PIN_9|GPIO_PIN_10|GPIO_PIN_11
                          |GPIO_PIN_12|GPIO_PIN_13;
  GPIO_InitStruct.Mode = GPIO_MODE_INPUT;
  GPIO_InitStruct.Pull = GPIO_NOPULL;
  HAL_GPIO_Init(GPIOE, &GPIO_InitStruct);

  /*Configure GPIO pins : PD11 PD14 */
  GPIO_InitStruct.Pin = GPIO_PIN_11|GPIO_PIN_14;
  GPIO_InitStruct.Mode = GPIO_MODE_OUTPUT_PP;
  GPIO_InitStruct.Pull = GPIO_NOPULL;
  GPIO_InitStruct.Speed = GPIO_SPEED_FREQ_LOW;
  HAL_GPIO_Init(GPIOD, &GPIO_InitStruct);

  /*Configure GPIO pins : PC6 PC8 PC12 */
  GPIO_InitStruct.Pin = GPIO_PIN_6|GPIO_PIN_8|GPIO_PIN_12;
  GPIO_InitStruct.Mode = GPIO_MODE_OUTPUT_PP;
  GPIO_InitStruct.Pull = GPIO_NOPULL;
  GPIO_InitStruct.Speed = GPIO_SPEED_FREQ_LOW;
  HAL_GPIO_Init(GPIOC, &GPIO_InitStruct);

  /*Configure GPIO pins : PA8 PA10 PA12 */
  GPIO_InitStruct.Pin = GPIO_PIN_8|GPIO_PIN_10|GPIO_PIN_12;
  GPIO_InitStruct.Mode = GPIO_MODE_OUTPUT_PP;
  GPIO_InitStruct.Pull = GPIO_NOPULL;
  GPIO_InitStruct.Speed = GPIO_SPEED_FREQ_LOW;
  HAL_GPIO_Init(GPIOA, &GPIO_InitStruct);

  /*Configure GPIO pins : PD1 PD3 */
  GPIO_InitStruct.Pin = GPIO_PIN_1|GPIO_PIN_3;
  GPIO_InitStruct.Mode = GPIO_MODE_INPUT;
  GPIO_InitStruct.Pull = GPIO_NOPULL;
  HAL_GPIO_Init(GPIOD, &GPIO_InitStruct);


}

void StartDefaultTask(void *argument)
{

  for(;;)
  {
    osDelay(1);
  }

}




#ifdef USE_FULL_ASSERT

void assert_failed(uint8_t *file, uint32_t line)
{

}
#endif /* USE_FULL_ASSERT */

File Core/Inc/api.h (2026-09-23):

#ifndef API_H
#define API_H
/*
 * api.h
 * -----
 * IEC-61131-style function-block library: latches, timers, counters,
 * edge detectors, comparators, scaling, math, and a PID block.
 *
 * This module is hardware-independent aside from PLC_TIME_MS, and is
 * one of the pieces of the original codebase that is already suitable
 * as reusable "platform" code (see analysis, section "PLC suitability").
 *
 * CHANGE LOG vs. original:
 *  - PID_Compact_Run: added anti-windup clamp on the integral
 *    accumulator (Finding #7). Previously only the final output was
 *    clamped; the integral term itself could wind up unbounded during
 *    sustained large error.
 */

#include <stdint.h>
#include <stdbool.h>

#include "cmsis_os2.h"
#define PLC_TIME_MS (osKernelGetTickCount())
/*
 * TODO (future, not applied here): make the time source injectable
 * (e.g. a weak PLC_GetTimeMs() or function pointer) instead of hard-
 * wiring osKernelGetTickCount(), so this library can run under a PC
 * simulator/Renode harness without an RTOS. See analysis, "Timer/
 * Counter Engine" section.
 */

/* ---------------------------------------------------------------- */
/* Contacts                                                          */
/* ---------------------------------------------------------------- */
static inline bool NO(bool signal) { return signal; }
static inline bool NC(bool signal) { return !signal; }

/* ---------------------------------------------------------------- */
/* Comparators                                                       */
/* ---------------------------------------------------------------- */
static inline uint8_t EQ_I(int in1, int in2) { return (in1 == in2) ? 1 : 0; }
static inline uint8_t GE_R(float in1, float in2) { return (in1 >= in2) ? 1 : 0; }
static inline uint8_t LT_R(float in1, float in2) { return (in1 < in2) ? 1 : 0; }

/* ---------------------------------------------------------------- */
/* Math                                                               */
/* ---------------------------------------------------------------- */
static inline int ADD_I(int in1, int in2) { return in1 + in2; }

static inline float DIV_R(float in1, float in2)
{
    if (in2 == 0.0f) return 0.0f;   /* Siemens-style: 0 on div-by-zero */
    return in1 / in2;
}

/* ---------------------------------------------------------------- */
/* Scaling                                                            */
/* ---------------------------------------------------------------- */
static inline float SCALE_X(float value, float min, float max)
{
    if (value < 0.0f)    value = 0.0f;
    if (value > 4095.0f) value = 4095.0f;
    return ((value / 4095.0f) * (max - min)) + min;
}

static inline uint16_t UNSCALE_X(float percent)
{
    if (percent < 0.0f)   percent = 0.0f;
    if (percent > 100.0f) percent = 100.0f;
    return (uint16_t)((percent / 100.0f) * 4095.0f);
}

static inline float MOVE(float in) { return in; }

static inline float MUX(uint8_t K, float IN0, float IN1, float IN2, float IN3)
{
    switch (K) {
        case 0:  return IN0;
        case 1:  return IN1;
        case 2:  return IN2;
        case 3:  return IN3;
        default: return IN0; /* Siemens fallback: out-of-range -> IN0 */
    }
}

/* ================================================================ */
/* Latches                                                            */
/* ================================================================ */

/* --- SR (Set-dominant) --- */
typedef struct { bool Q; } SR_Instance;

static inline bool SR_Run(SR_Instance *inst, bool S, bool R)
{
    if (S) inst->Q = 1;
    if (R) inst->Q = 0;
    return inst->Q;
}

#define SR(S, R) \
    ({ static SR_Instance inst = {0}; SR_Run(&inst, S, R); })

/* --- RS (Reset-dominant) --- */
typedef struct { bool Q; } RS_Instance;

static inline bool RS_Run(RS_Instance *inst, bool S, bool R)
{
    if (R) inst->Q = 1;
    if (S) inst->Q = 0;
    return inst->Q;
}

#define RS(S, R) \
    ({ static RS_Instance inst = {0}; RS_Run(&inst, S, R); })

/* ================================================================ */
/* Timers                                                             */
/* ================================================================ */

/* --- TON: on-delay --- */
typedef struct {
    bool IN; uint32_t PT;
    bool Q;  uint32_t ET;
    uint32_t start_time;
    bool running;
} TON_Instance;

static inline void TON_Run(TON_Instance *inst)
{
    if (inst->IN) {
        if (!inst->running) {
            inst->running = true;
            inst->start_time = PLC_TIME_MS;
        }
        inst->ET = PLC_TIME_MS - inst->start_time;
        if (inst->ET >= inst->PT) {
            inst->Q = true;
            inst->ET = inst->PT;
        } else {
            inst->Q = false;
        }
    } else {
        inst->Q = false;
        inst->ET = 0;
        inst->running = false;
    }
}

#define TON(NAME, IN_VALUE, PT_VALUE) \
    do { NAME.IN = IN_VALUE; NAME.PT = PT_VALUE; TON_Run(&NAME); } while (0)

/* --- TOF: off-delay --- */
typedef struct {
    bool IN; uint32_t PT;
    bool Q;  uint32_t ET;
    uint32_t start_time;
    bool timing;
} TOF_Instance;

static inline void TOF_Run(TOF_Instance *inst)
{
    if (inst->IN) {
        inst->Q = true;
        inst->ET = 0;
        inst->timing = false;
    } else {
        if (inst->Q && !inst->timing) {
            inst->timing = true;
            inst->start_time = PLC_TIME_MS;
        }
        if (inst->timing) {
            inst->ET = PLC_TIME_MS - inst->start_time;
            if (inst->ET >= inst->PT) {
                inst->Q = false;
                inst->ET = inst->PT;
                inst->timing = false;
            }
        }
    }
}

#define TOF(NAME, IN_VALUE, PT_VALUE) \
    do { NAME.IN = IN_VALUE; NAME.PT = PT_VALUE; TOF_Run(&NAME); } while (0)

/* --- TP: pulse --- */
typedef struct {
    bool IN; uint32_t PT;
    bool Q;  uint32_t ET;
    bool prev_IN;
    uint32_t start_time;
    bool running;
} TP_Instance;

static inline void TP_Run(TP_Instance *inst)
{
    bool rising_edge = (inst->IN && !inst->prev_IN);
    inst->prev_IN = inst->IN;

    if (rising_edge) {
        inst->running = true;
        inst->start_time = PLC_TIME_MS;
        inst->Q = true;
    }

    if (inst->running) {
        inst->ET = PLC_TIME_MS - inst->start_time;
        if (inst->ET >= inst->PT) {
            inst->Q = false;
            inst->ET = inst->PT;
            inst->running = false;
        }
    } else {
        inst->ET = 0;
    }
}

#define TP(NAME, IN_VALUE, PT_VALUE) \
    do { NAME.IN = IN_VALUE; NAME.PT = PT_VALUE; TP_Run(&NAME); } while (0)

/* ================================================================ */
/* Counters                                                           */
/* ================================================================ */
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

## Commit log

2026-09-23 Initial commit: STM32 PLC firmware
2026-09-25 PCB design
    [mpuled.kicad_pcb, mpuled.kicad_sch]
